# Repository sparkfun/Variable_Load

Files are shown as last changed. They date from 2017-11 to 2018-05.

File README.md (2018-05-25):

SparkFun Variable Load
==========================================

Variable Load

[*Variable Load (KIT-14449)*](https://www.sparkfun.com/products/14449)

The Variable Load is a digitally controllable load for testing power supplies.
It can test up to 30V at 4A, with a limit of 15W.

Repository Contents
-------------------
* **/Hardware** - All Eagle design files (.brd, .sch)
* **/Firmware** - Firmware files for this project.
* **/Production** - Test bed files and production panel files

Documentation
--------------

* **[Hookup Guide - Revised](https://learn.sparkfun.com/tutorials/variable-load-hookup-guide---revised)** - Latest basic hookup guide for the Variable Load.
* ***[Hookup Guide (RETIRED)](https://learn.sparkfun.com/tutorials/variable-load-hookup-guide)** - Basic hookup guide for the Variable Load for boards purchased purchased prior to 24 May 2018.*

License Information
-------------------

This product is _**open source**_! 

Please review the LICENSE.md file for license information. 

If you have any questions or concerns on licensing, please contact techsupport@sparkfun.com.

Distributed as-is; no warranty is given.

- Your friends at SparkFun.

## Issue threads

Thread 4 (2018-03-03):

PID issue with negative error

keck9939, 2018-03-03:
If the error term in the PID calculation is negative, I believe the PID calculation falls apart. For example, if iLimit is 1.0 and iSource is 1.1, it calculates grossSetPoint = 0, fineSetPoint = 65533. Since for iSource = 0.9 you get grossSetPoint = 1 and fineSetPoint = 2, and for 0 error you get 0, there is clearly something wrong (the PID output should be a continuous function of the input). Looking at the code, it is clear there was no thought given to handling negative PID output. While it is possible the load may appear to operate correctly, I strongly suspect it is subject to overshoot and instability.

calston, 2018-04-22:
I think this is the same issue I’m reproducing when the supply current limits and the I value goes below the loads limit setting. Your fix is a total rewrite though, which is a bit hard to review although probably not unwarranted given the quality

But since apparently no one at Sparkfun cares about this product sucking horribly maybe we should just fork this off to a different project so PRs actually go anywhere?

keck9939, 2018-04-22:
I rewrote it since I found there were a number of short comings and I wanted to add a mAh computation to use it to evaluate batteries. I forked it (keck9939/Variable_Load), but I am a GitHub newbie so I was hoping Sparkfun would respond to my pull request so I didn't have to become a maintainer. I doubt it is a hot seller which may explain Sparkfun's lack of interest. I would not have bought it if I didn't already have experience with PSoCs since I figured I'd want to modify it.

calston, 2018-04-23:
I also intended to modify it but was not expecting how expensive that would be.

keck9939, 2018-04-23:
FYI, the cheapest way to get a programmer is to buy one of the Cypress PSoC dev boards. For example the CY8KIT-059 is $15. It includes a breakaway KitProg which can be used to program the Sparkfun board. Much cheaper than buying a MiniProg. And you might even find a use for the dev board (PSoCs rock!)

calston, 2018-04-23:
I've ordered one of those but $15 turns into much more with customs and shipping to the middle of nowhere here...

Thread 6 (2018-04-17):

Enable/disable load via serial

calston, 2018-04-17:
I'm not entirely sure how to implement this, but it would be nice to be able to enable the load remotely rather than the buttons.

calston, 2018-04-17:
Gees, apparently I have to buy a dev kit just to reflash this thing

keck9939, 2018-04-22:
Cypress provides a boot-load system that would allow re-flashing without a programmer. Unfortunately, Sparkfun did not implement it.

jbcall90, 2021-07-04:
Per the revised Variable Load Hookup Guide, boards shipped after 24 May 2018 include the bootloader. The revised Variable Load Hookup Guide includes detailed and adequate instructions on how to use PSoC Creator to upload firmware changes.

The firmware included on the kit I received in June 2021 includes the feature to enable and disable the load using the serial connection.

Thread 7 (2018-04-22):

Variable load behaves unexpectedly on a current limited source

calston, 2018-04-22:
Connecting the Variable Load to a current limited source yields highly unexpected results.

The load shuts off entirely letting the source recover somewhat and then turns on again, cycling like that without equilibrium

mhord, 2018-04-23:
This is exactly the behavior I would expect:
1. The supply's current limit is exceeded.
2. The supply voltage folds back.
3. Supply voltage drops below variable load minimum voltage.
4. Variable load shuts off since its minimum voltage check has been violated.
5. No load on supply so supply exits foldback and rebounds.
6. Etc.

calston, 2018-04-24:
That makes no sense at all. The load is a current device, the voltage from the limited supply drops slightly to maintain constant power. Why on earth would the load shut itself off when the voltage reduces only slightly?

calston, 2018-04-24:
The virtual resistance of the load should increase proportional to the voltage to maintain a constant load. Instead it shuts off? Did you actually test this before rubbishing my ticket?

mhord, 2018-04-24:
The new version of firmware will disable the output until a user intervenes when the input dips below Vmin. That will prevent the cycling behavior you've seen.

mhord, 2018-04-24:
You'll note that I didn't say that the supply "shuts down", I said it "folds back". That means reducing the voltage until the current stabilizes at the limit.

The variable load won't attempt to keep drawing current if the voltage is below 2V. I suspect that if you were to watch the output of your load on a scope you'd see it oscillating above and below 2V as the load kicks on and off. Can you verify this? Again, that's the expected outcome.

The newer version of the code, contributed by keck9939, disables the load once the voltage dips below 2V and doesn't reenable it until the user intervenes. I find this to be a preferable state of affairs.

Closed 2018-04-23.

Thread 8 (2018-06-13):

V Source limits at 20.48V

steaky1212, 2018-06-13:
V Source will not exceed 20.48V

steaky1212, 2018-06-13:
Somehow TopDesign.cysch Page1 Source_ADC was set to "0.0 to 2.048V" instead of "Vssa to Vdda".
Once changed to "Vssa to Vdda" this worked fine again

Closed 2018-06-13.

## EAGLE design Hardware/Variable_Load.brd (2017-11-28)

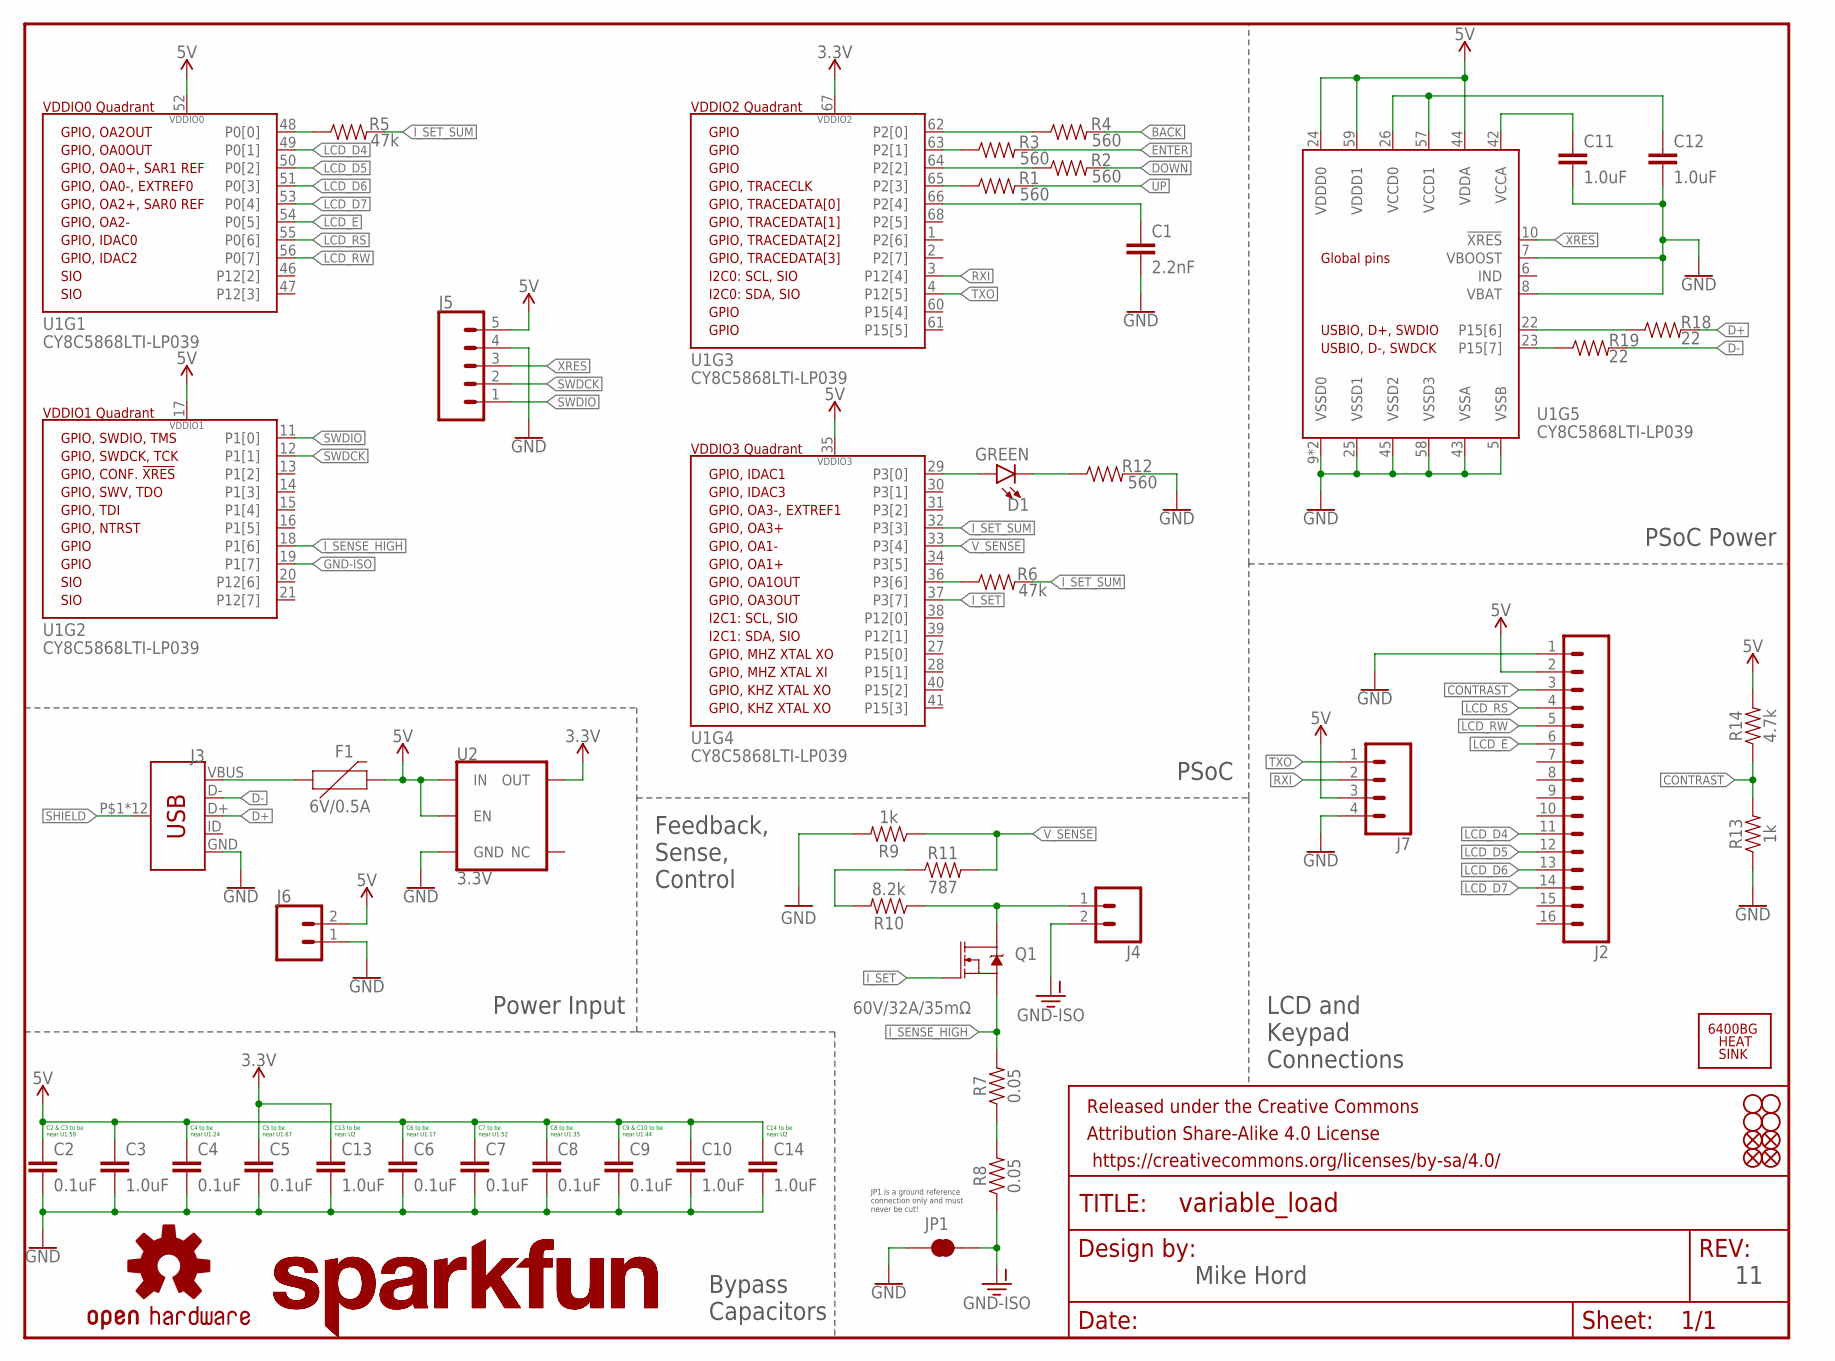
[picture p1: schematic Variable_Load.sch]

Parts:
C1: 2.2nF; 0603
C2, C4, C5, C6, C7, C8, C9: 0.1uF; 0402
C3, C10, C11, C12, C13, C14: 1.0uF; 0402
D1: GREEN; LED-1206-BOTTOM
F1: 6V/0.5A; 1206
FD1, FD2, FD3, FD4: FIDUCIAL1X2; FIDUCIAL-1X2
FRAME1: FRAME-LETTER; CREATIVE_COMMONS
H1: 6400BG_HEATSINK
H2, H3, H4, H5: STAND-OFF
J2: CONN_16; 1X16
J3: AMP FCI 10103594-0001LF; USB-MICROB-PTH
J4: CONN_023.5MM_LOCK; SCREWTERMINAL-3.5MM-2_LOCK
J5: CONN_05; 1X05
J6: CONN_02; 1X02
J7: CONN_04; 1X04
JP1: JUMPER-SMT_2_NC_TRACE_NO-SILK; SMT-JUMPER_2_NC_TRACE_NO-SILK
LOGO1: OSHW-LOGOM; OSHW-LOGO-M
LOGO2, LOGO3: SFE_LOGO_NAME.3_INCH; SFE_LOGO_NAME_.3
Q1: 60V/32A/35mΩ; TO220V
R1, R2, R3, R4, R12: 560; 0402
R5, R6: 47k; 0603
R7, R8: 0.05; 2512
R9, R13: 1k; 0603
R10: 8.2k; 0603
R11: 787; 0603
R14: 4.7k; 0603
R18, R19: 22; 0402-RES
U1: CY8C5868LTI-LP039; QFN-68
U2: 3.3V; SOT23-5

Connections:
3.3V: C5.1, C13.1, U1.67 (VDDIO2), U2.5 (OUT)
5V: C2.1, C3.1, C4.1, C6.1, C7.1, C8.1, C9.1, C10.1, C14.1, F1.2, J2.2, J5.5, J6.2, J7.3, R14.2, U1.17 (VDDIO1), U1.24 (VDDD0), U1.35 (VDDIO3), U1.44 (VDDA), U1.52 (VDDIO0), U1.59 (VDDD1), U2.1 (IN), U2.3 (EN)
BACK: R4.2
CONTRAST: J2.3, R13.2, R14.1
D+: J3.D+, R18.2
D-: J3.D-, R19.2
DOWN: R2.2
ENTER: R3.2
GND: C1.2, C2.2, C3.2, C4.2, C5.2, C6.2, C7.2, C8.2, C9.2, C10.2, C11.2, C12.2, C13.2, C14.2, J2.1, J3.GND, J5.4, J6.1, J7.4, JP1.1, R9.2, R12.2, R13.1, U1.5 (VSSB), U1.7 (VBOOST), U1.8 (VBAT), U1.9 (VSSD0), U1.25 (VSSD1), U1.43 (VSSA), U1.45 (VSSD2), U1.58 (VSSD3), U1.69 (VSSD0), U2.2 (GND)
GND-ISO: J4.2, JP1.2, R8.P$1 (1), U1.19 (P1[7])
I_SENSE_HIGH: Q1.3 (S), R7.P$2 (2), U1.18 (P1[6])
I_SET: Q1.1 (G), U1.37 (P3[7])
I_SET_SUM: R5.2, R6.2, U1.32 (P3[3])
LCD_D4: J2.11, U1.49 (P0[1])
LCD_D5: J2.12, U1.50 (P0[2])
LCD_D6: J2.13, U1.51 (P0[3])
LCD_D7: J2.14, U1.53 (P0[4])
LCD_E: J2.6, U1.54 (P0[5])
LCD_RS: J2.4, U1.55 (P0[6])
LCD_RW: J2.5, U1.56 (P0[7])
unnamed: R1.1, U1.65 (P2[3])
unnamed: R2.1, U1.64 (P2[2])
unnamed: R3.1, U1.63 (P2[1])
unnamed: R4.1, U1.62 (P2[0])
unnamed: C1.1, U1.66 (P2[4])
unnamed: C12.1, U1.26 (VCCD0), U1.57 (VCCD1)
unnamed: C11.1, U1.42 (VCCA)
unnamed: R18.1, U1.22 (P15[6])
unnamed: R19.1, U1.23 (P15[7])
unnamed: R5.1, U1.48 (P0[0])
unnamed: R6.1, U1.36 (P3[6])
unnamed: D1.A, U1.29 (P3[0])
unnamed: D1.C, R12.1
unnamed: F1.1, J3.VBUS
unnamed: J4.1, Q1.2 (D), R10.1
unnamed: R10.2, R11.1
unnamed: R7.P$1 (1), R8.P$2 (2)
RXI: J7.2, U1.3 (P12[4])
SHIELD: J3.P$1 (SHIELD), J3.P$2 (SHIELD), J3.P$3 (SHIELD), J3.P$4 (SHIELD), J3.P$6 (SHIELD), J3.P$8 (SHIELD), J3.P$10 (SHIELD), J3.P$12 (SHIELD), J3.SHEILD2 (SHIELD), J3.SHIELD, J3.SHIELD3 (SHIELD), J3.SHIELD4 (SHIELD)
SWDCK: J5.2, U1.12 (P1[1])
SWDIO: J5.1, U1.11 (P1[0])
TXO: J7.1, U1.4 (P12[5])
UP: R1.2
V_SENSE: R9.1, R11.2, U1.33 (P3[4])
XRES: J5.3, U1.10 (!XRES)

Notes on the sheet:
C2 & C3 to be near U1.59
C4 to be near U1.24
C5 to be near U1.67
C6 to be near U1.17
C7 to be near U1.52
C8 to be near U1.35
C9 & C10 to be near U1.44
C13 to be near U2
C14 to be near U2
Feedback, Sense, Control
Power Input
LCD and Keypad Connections
PSoC Power
PSoC
Bypass Capacitors
Mike Hord
JP1 is a ground reference connection only and must never be cut!

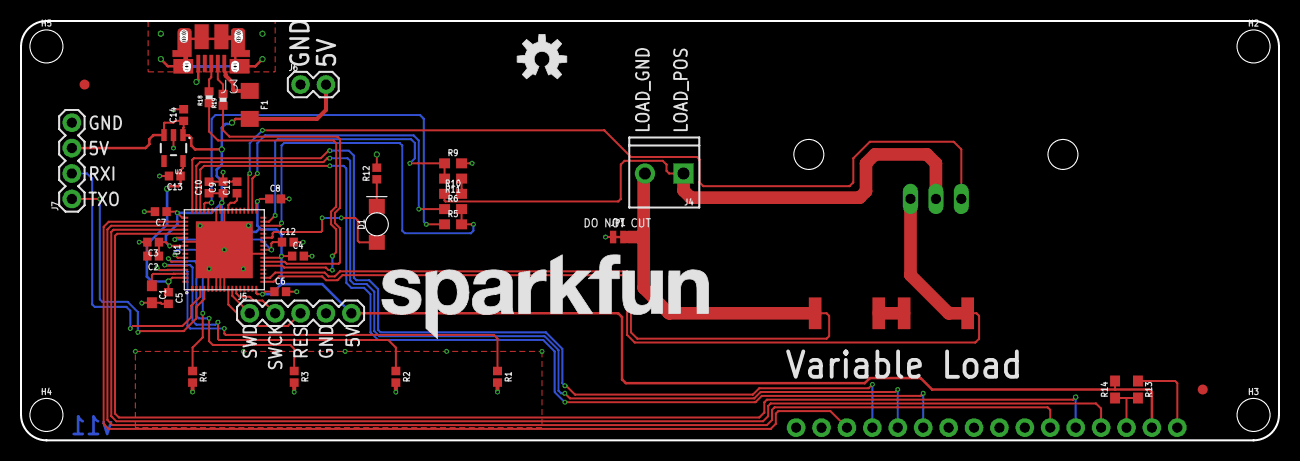
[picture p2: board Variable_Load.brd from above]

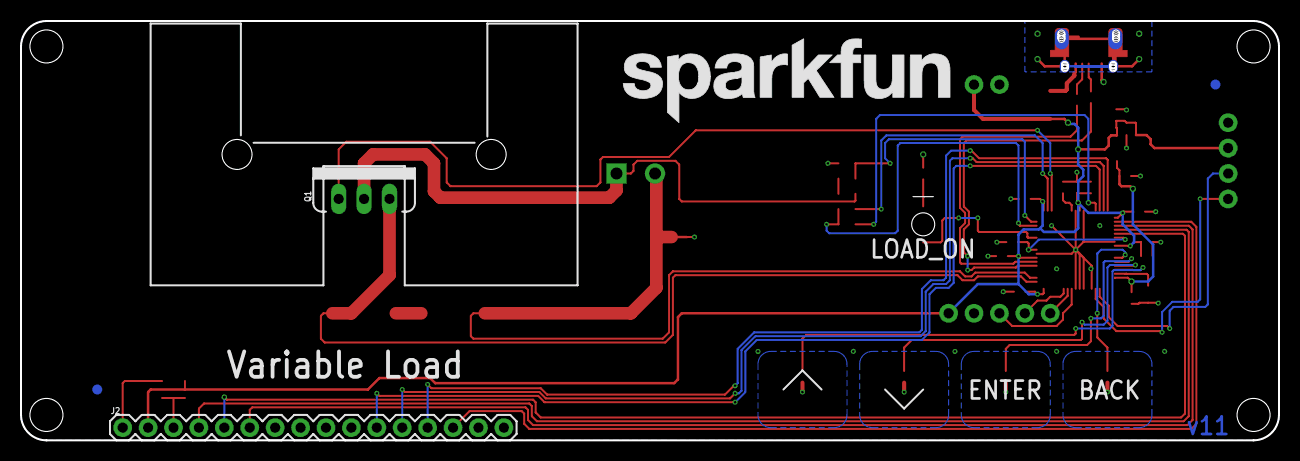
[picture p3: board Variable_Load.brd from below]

Board: 2 copper layers, 125.7 x 41.9 mm, 55 parts (6 on the bottom side), 41 nets.

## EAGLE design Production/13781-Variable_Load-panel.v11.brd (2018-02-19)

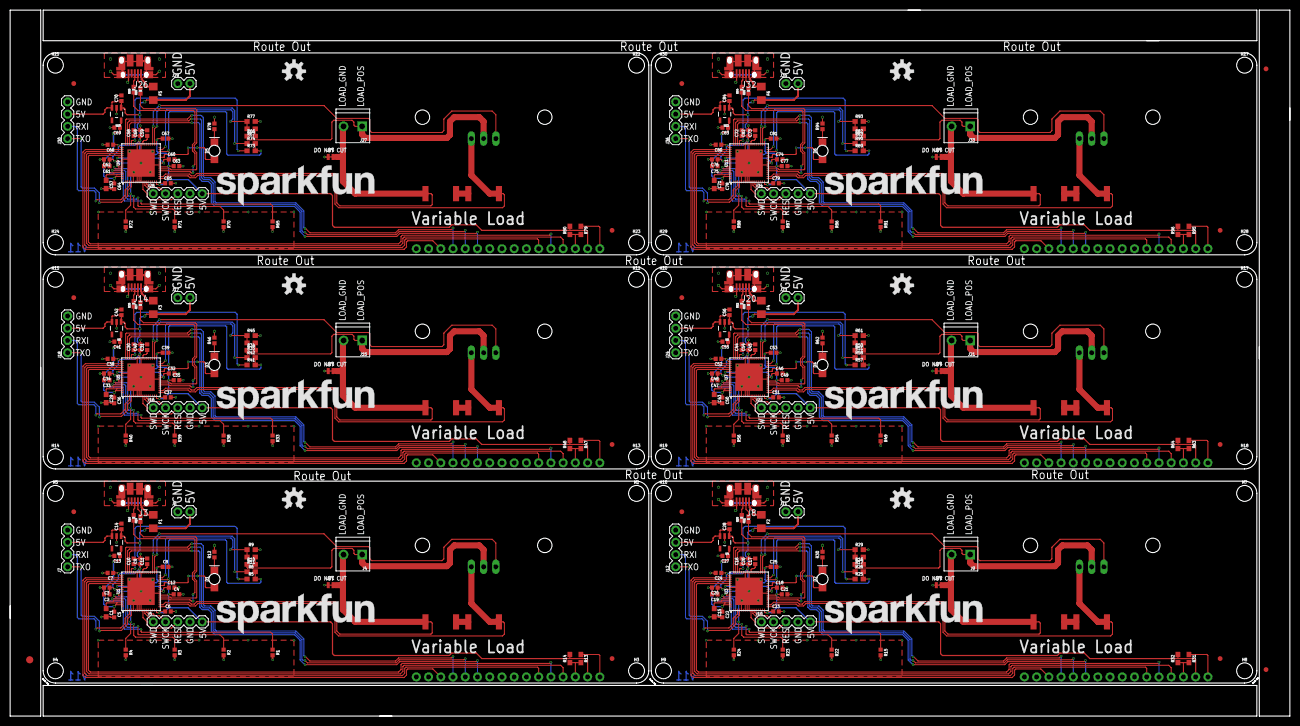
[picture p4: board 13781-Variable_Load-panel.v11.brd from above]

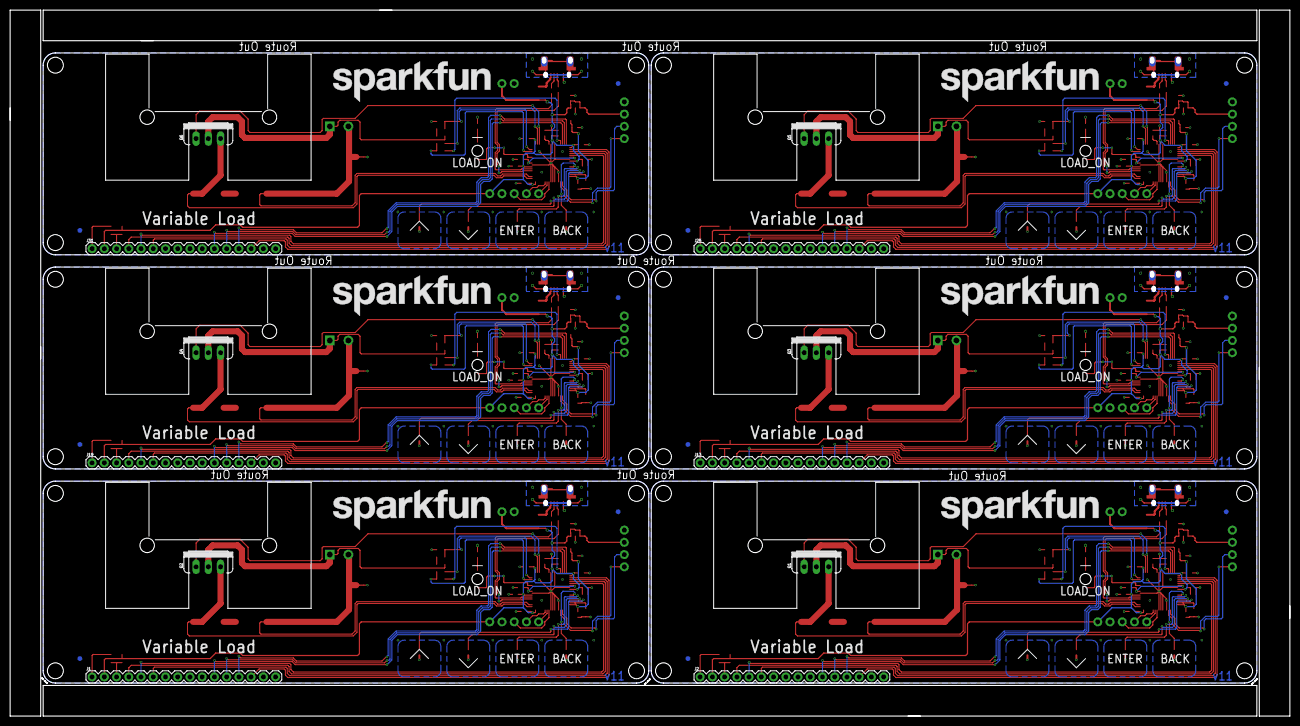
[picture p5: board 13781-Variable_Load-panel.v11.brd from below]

Board: 2 copper layers, 265.7 x 146.6 mm, 327 parts (36 on the bottom side), 246 nets.

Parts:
C1, C15, C29, C43, C57, C71: 2.2nF; 0603
C2, C4, C5, C6, C7, C8, C9, C19, C21, C22, C23, C24, C25, C26, C33, C35, C36, C37, C38, C39, C40, C47, C49, C50, C51, C52, C53, C54, C61, C63, C64, C65, C66, C67, C68, C75, C77, C78, C79, C80, C81, C82: 0.1uF; 0402
C3, C10, C11, C12, C13, C14, C16, C17, C18, C20, C27, C28, C30, C31, C32, C34, C41, C42, C44, C45, C46, C48, C55, C56, C58, C59, C60, C62, C69, C70, C72, C73, C74, C76, C83, C84: 1.0uF; 0402
D1, D2, D3, D4, D5, D6: GREEN; LED-1206-BOTTOM
E$1: FIDUCIAL-1.5X3
E$7, E$8: FIDUCIAL-1X2
F1, F2, F3, F4, F5, F6: 6V/0.5A; 1206
FD1, FD2, FD3, FD4, FD5, FD6, FD7, FD8, FD9, FD10, FD11, FD12, FD13, FD14, FD15, FD16, FD17, FD18, FD19, FD20, FD21, FD22, FD23, FD24: FIDUCIAL1X2; FIDUCIAL-1X2
H1, H6, H11, H16, H21, H26: 6400BG_HEATSINK
H2, H3, H4, H5, H7, H8, H9, H10, H12, H13, H14, H15, H17, H18, H19, H20, H22, H23, H24, H25, H27, H28, H29, H30: STAND-OFF
J1, J2, J13, J19, J25, J31: 1X16
J3, J8, J14, J20, J26, J32: AMP FCI 10103594-0001LF; USB-MICROB-PTH
J4, J9, J15, J21, J27, J33: SCREWTERMINAL-3.5MM-2_LOCK
J5, J10, J16, J22, J28, J34: 1X05
J6, J11, J17, J23, J29, J35: 1X02
J7, J12, J18, J24, J30, J36: 1X04
JP1, JP2, JP3, JP4, JP5, JP6: JUMPER-SMT_2_NC_TRACE_NO-SILK; SMT-JUMPER_2_NC_TRACE_NO-SILK
LOGO1, LOGO4, LOGO7, LOGO10, LOGO13, LOGO16: OSHW-LOGOM; OSHW-LOGO-M
LOGO2, LOGO3, LOGO5, LOGO6, LOGO8, LOGO9, LOGO11, LOGO12, LOGO14, LOGO15, LOGO17, LOGO18: SFE_LOGO_NAME.3_INCH; SFE_LOGO_NAME_.3
Q1, Q2, Q3, Q4, Q5, Q6: 60V/32A/35mΩ; TO220V
R1, R2, R3, R4, R12, R15, R22, R23, R24, R30, R33, R38, R39, R40, R46, R49, R54, R55, R56, R62, R65, R70, R71, R72, R78, R81, R86, R87, R88, R94: 560; 0402
R5, R6, R25, R26, R41, R42, R57, R58, R73, R74, R89, R90: 47k; 0603
R7, R8, R27, R28, R43, R44, R59, R60, R75, R76, R91, R92: 0.05; 2512
R9, R13, R29, R31, R45, R47, R61, R63, R77, R79, R93, R95: 1k; 0603
R10, R16, R34, R50, R66, R82: 8.2k; 0603
R11, R17, R35, R51, R67, R83: 787; 0603
R14, R32, R48, R64, R80, R96: 4.7k; 0603
R18, R19, R20, R21, R36, R37, R52, R53, R68, R69, R84, R85: 22; 0402-RES
U1, U3, U5, U7, U9, U11: CY8C5868LTI-LP039; QFN-68
U2, U4, U6, U8, U10, U12: 3.3V; SOT23-5

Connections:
3.3V: C5.1, C13.1, U1.67, U2.5
3.3V1: C22.1, C27.1, U3.67, U4.5
3.3V2: C36.1, C41.1, U5.67, U6.5
3.3V3: C50.1, C55.1, U7.67, U8.5
3.3V4: C64.1, C69.1, U9.67, U10.5
3.3V5: C78.1, C83.1, U11.67, U12.5
5V: C2.1, C3.1, C4.1, C6.1, C7.1, C8.1, C9.1, C10.1, C14.1, F1.2, J2.2, J5.5, J6.2, J7.3, R14.2, U1.17, U1.24, U1.35, U1.44, U1.52, U1.59, U2.1, U2.3
5V1: C16.1, C19.1, C20.1, C21.1, C23.1, C24.1, C25.1, C26.1, C28.1, F2.2, J1.2, J10.5, J11.2, J12.3, R32.2, U3.17, U3.24, U3.35, U3.44, U3.52, U3.59, U4.1, U4.3
5V2: C30.1, C33.1, C34.1, C35.1, C37.1, C38.1, C39.1, C40.1, C42.1, F3.2, J13.2, J16.5, J17.2, J18.3, R48.2, U5.17, U5.24, U5.35, U5.44, U5.52, U5.59, U6.1, U6.3
5V3: C44.1, C47.1, C48.1, C49.1, C51.1, C52.1, C53.1, C54.1, C56.1, F4.2, J19.2, J22.5, J23.2, J24.3, R64.2, U7.17, U7.24, U7.35, U7.44, U7.52, U7.59, U8.1, U8.3
5V4: C58.1, C61.1, C62.1, C63.1, C65.1, C66.1, C67.1, C68.1, C70.1, F5.2, J25.2, J28.5, J29.2, J30.3, R80.2, U9.17, U9.24, U9.35, U9.44, U9.52, U9.59, U10.1, U10.3
5V5: C72.1, C75.1, C76.1, C77.1, C79.1, C80.1, C81.1, C82.1, C84.1, F6.2, J31.2, J34.5, J35.2, J36.3, R96.2, U11.17, U11.24, U11.35, U11.44, U11.52, U11.59, U12.1, U12.3
CONTRAST: J2.3, R13.2, R14.1
CONTRAST1: J1.3, R31.2, R32.1
CONTRAST2: J13.3, R47.2, R48.1
CONTRAST3: J19.3, R63.2, R64.1
CONTRAST4: J25.3, R79.2, R80.1
CONTRAST5: J31.3, R95.2, R96.1
D+: J3.D+, R18.2
D+1: J8.D+, R20.2
D+2: J14.D+, R36.2
D+3: J20.D+, R52.2
D+4: J26.D+, R68.2
D+5: J32.D+, R84.2
D-: J3.D-, R19.2
D-1: J8.D-, R21.2
D-2: J14.D-, R37.2
D-3: J20.D-, R53.2
D-4: J26.D-, R69.2
D-5: J32.D-, R85.2
GND: C1.2, C2.2, C3.2, C4.2, C5.2, C6.2, C7.2, C8.2, C9.2, C10.2, C11.2, C12.2, C13.2, C14.2, J2.1, J3.GND, J5.4, J6.1, J7.4, JP1.1, R9.2, R12.2, R13.1, U1.5, U1.7, U1.8, U1.9, U1.25, U1.43, U1.45, U1.58, U1.69, U2.2
GND1: C15.2, C16.2, C17.2, C18.2, C19.2, C20.2, C21.2, C22.2, C23.2, C24.2, C25.2, C26.2, C27.2, C28.2, J1.1, J8.GND, J10.4, J11.1, J12.4, JP2.1, R29.2, R30.2, R31.1, U3.5, U3.7, U3.8, U3.9, U3.25, U3.43, U3.45, U3.58, U3.69, U4.2
GND2: C29.2, C30.2, C31.2, C32.2, C33.2, C34.2, C35.2, C36.2, C37.2, C38.2, C39.2, C40.2, C41.2, C42.2, J13.1, J14.GND, J16.4, J17.1, J18.4, JP3.1, R45.2, R46.2, R47.1, U5.5, U5.7, U5.8, U5.9, U5.25, U5.43, U5.45, U5.58, U5.69, U6.2
GND3: C43.2, C44.2, C45.2, C46.2, C47.2, C48.2, C49.2, C50.2, C51.2, C52.2, C53.2, C54.2, C55.2, C56.2, J19.1, J20.GND, J22.4, J23.1, J24.4, JP4.1, R61.2, R62.2, R63.1, U7.5, U7.7, U7.8, U7.9, U7.25, U7.43, U7.45, U7.58, U7.69, U8.2
GND4: C57.2, C58.2, C59.2, C60.2, C61.2, C62.2, C63.2, C64.2, C65.2, C66.2, C67.2, C68.2, C69.2, C70.2, J25.1, J26.GND, J28.4, J29.1, J30.4, JP5.1, R77.2, R78.2, R79.1, U9.5, U9.7, U9.8, U9.9, U9.25, U9.43, U9.45, U9.58, U9.69, U10.2
GND5: C71.2, C72.2, C73.2, C74.2, C75.2, C76.2, C77.2, C78.2, C79.2, C80.2, C81.2, C82.2, C83.2, C84.2, J31.1, J32.GND, J34.4, J35.1, J36.4, JP6.1, R93.2, R94.2, R95.1, U11.5, U11.7, U11.8, U11.9, U11.25, U11.43, U11.45, U11.58, U11.69, U12.2
GND-ISO: J4.2, JP1.2, R8.P$1, U1.19
GND-ISO1: J9.2, JP2.2, R28.P$1, U3.19
GND-ISO2: J15.2, JP3.2, R44.P$1, U5.19
GND-ISO3: J21.2, JP4.2, R60.P$1, U7.19
GND-ISO4: J27.2, JP5.2, R76.P$1, U9.19
GND-ISO5: J33.2, JP6.2, R92.P$1, U11.19
I_SENSE_HIGH: Q1.3, R7.P$2, U1.18
I_SENSE_HIGH1: Q2.3, R27.P$2, U3.18
I_SENSE_HIGH2: Q3.3, R43.P$2, U5.18
I_SENSE_HIGH3: Q4.3, R59.P$2, U7.18
I_SENSE_HIGH4: Q5.3, R75.P$2, U9.18
I_SENSE_HIGH5: Q6.3, R91.P$2, U11.18
I_SET: Q1.1, U1.37
I_SET1: Q2.1, U3.37
I_SET2: Q3.1, U5.37
I_SET3: Q4.1, U7.37
I_SET4: Q5.1, U9.37
I_SET5: Q6.1, U11.37
I_SET_SUM: R5.2, R6.2, U1.32
I_SET_SUM1: R25.2, R26.2, U3.32
I_SET_SUM2: R41.2, R42.2, U5.32
I_SET_SUM3: R57.2, R58.2, U7.32
I_SET_SUM4: R73.2, R74.2, U9.32
I_SET_SUM5: R89.2, R90.2, U11.32
LCD_D1: J1.11, U3.49
LCD_D2: J1.12, U3.50
LCD_D3: J1.13, U3.51
LCD_D4: J2.11, U1.49
LCD_D5: J2.12, U1.50
LCD_D6: J2.13, U1.51
LCD_D7: J2.14, U1.53
LCD_D8: J1.14, U3.53
LCD_D9: J13.11, U5.49
LCD_D10: J13.12, U5.50
LCD_D11: J13.13, U5.51
LCD_D12: J13.14, U5.53
LCD_D13: J19.11, U7.49
LCD_D14: J19.12, U7.50
LCD_D15: J19.13, U7.51
LCD_D16: J19.14, U7.53
LCD_D17: J25.11, U9.49
LCD_D18: J25.12, U9.50
LCD_D19: J25.13, U9.51
LCD_D20: J25.14, U9.53
LCD_D21: J31.11, U11.49
LCD_D22: J31.12, U11.50
LCD_D23: J31.13, U11.51
LCD_D24: J31.14, U11.53
LCD_E: J2.6, U1.54
LCD_E1: J1.6, U3.54
LCD_E2: J13.6, U5.54
LCD_E3: J19.6, U7.54
LCD_E4: J25.6, U9.54
LCD_E5: J31.6, U11.54
LCD_RS: J2.4, U1.55
LCD_RS1: J1.4, U3.55
LCD_RS2: J13.4, U5.55
LCD_RS3: J19.4, U7.55
LCD_RS4: J25.4, U9.55
LCD_RS5: J31.4, U11.55
LCD_RW: J2.5, U1.56
LCD_RW1: J1.5, U3.56
LCD_RW2: J13.5, U5.56
LCD_RW3: J19.5, U7.56
LCD_RW4: J25.5, U9.56
LCD_RW5: J31.5, U11.56
unnamed: R1.1, U1.65
unnamed: R2.1, U1.64
unnamed: R3.1, U1.63
unnamed: R4.1, U1.62
unnamed: C1.1, U1.66
unnamed: C12.1, U1.26, U1.57
unnamed: C11.1, U1.42
unnamed: R18.1, U1.22
unnamed: R19.1, U1.23
unnamed: R5.1, U1.48
unnamed: R6.1, U1.36
unnamed: D1.A, U1.29
unnamed: D1.C, R12.1
unnamed: F1.1, J3.VBUS
unnamed: J4.1, Q1.2, R10.1
unnamed: R10.2, R11.1
unnamed: C15.1, U3.66
unnamed: R7.P$1, R8.P$2
unnamed: R25.1, U3.48
unnamed: C18.1, U3.26, U3.57
unnamed: C17.1, U3.42
unnamed: R20.1, U3.22
unnamed: R21.1, U3.23
unnamed: F2.1, J8.VBUS
unnamed: J9.1, Q2.2, R16.1
unnamed: R16.2, R17.1
unnamed: R27.P$1, R28.P$2
unnamed: R15.1, U3.65
unnamed: R22.1, U3.64
unnamed: R23.1, U3.63
unnamed: R24.1, U3.62
unnamed: R26.1, U3.36
unnamed: D2.A, U3.29
unnamed: D2.C, R30.1
unnamed: C29.1, U5.66
unnamed: R41.1, U5.48
unnamed: C32.1, U5.26, U5.57
unnamed: C31.1, U5.42
unnamed: R36.1, U5.22
unnamed: R37.1, U5.23
unnamed: F3.1, J14.VBUS
unnamed: J15.1, Q3.2, R34.1
unnamed: R34.2, R35.1
unnamed: R43.P$1, R44.P$2
unnamed: R33.1, U5.65
unnamed: R38.1, U5.64
unnamed: R39.1, U5.63
unnamed: R40.1, U5.62
unnamed: R42.1, U5.36
unnamed: D3.A, U5.29
unnamed: D3.C, R46.1
unnamed: C43.1, U7.66
unnamed: R57.1, U7.48
unnamed: C46.1, U7.26, U7.57
unnamed: C45.1, U7.42
unnamed: R52.1, U7.22
unnamed: R53.1, U7.23
unnamed: F4.1, J20.VBUS
unnamed: J21.1, Q4.2, R50.1
unnamed: R50.2, R51.1
unnamed: R59.P$1, R60.P$2
unnamed: R49.1, U7.65
unnamed: R54.1, U7.64
unnamed: R55.1, U7.63
unnamed: R56.1, U7.62
unnamed: R58.1, U7.36
unnamed: D4.A, U7.29
unnamed: D4.C, R62.1
unnamed: C57.1, U9.66
unnamed: R73.1, U9.48
unnamed: C60.1, U9.26, U9.57
unnamed: C59.1, U9.42
unnamed: R68.1, U9.22
unnamed: R69.1, U9.23
unnamed: F5.1, J26.VBUS
unnamed: J27.1, Q5.2, R66.1
unnamed: R66.2, R67.1
unnamed: R75.P$1, R76.P$2
unnamed: R65.1, U9.65
unnamed: R70.1, U9.64
unnamed: R71.1, U9.63
unnamed: R72.1, U9.62
unnamed: R74.1, U9.36
unnamed: D5.A, U9.29
unnamed: D5.C, R78.1
unnamed: C71.1, U11.66
unnamed: R89.1, U11.48
unnamed: C74.1, U11.26, U11.57
unnamed: C73.1, U11.42
unnamed: R84.1, U11.22
unnamed: R85.1, U11.23
unnamed: F6.1, J32.VBUS
unnamed: J33.1, Q6.2, R82.1
unnamed: R82.2, R83.1
unnamed: R91.P$1, R92.P$2
unnamed: R81.1, U11.65
unnamed: R86.1, U11.64
unnamed: R87.1, U11.63
unnamed: R88.1, U11.62
unnamed: R90.1, U11.36
unnamed: D6.A, U11.29
unnamed: D6.C, R94.1
RXI: J7.2, U1.3
RXI1: J12.2, U3.3
RXI2: J18.2, U5.3
RXI3: J24.2, U7.3
RXI4: J30.2, U9.3
RXI5: J36.2, U11.3
SHIELD: J3.P$1, J3.P$2, J3.P$3, J3.P$4, J3.P$6, J3.P$8, J3.P$10, J3.P$12, J3.SHEILD2, J3.SHIELD, J3.SHIELD3, J3.SHIELD4
SHIELD1: J8.P$1, J8.P$2, J8.P$3, J8.P$4, J8.P$6, J8.P$8, J8.P$10, J8.P$12, J8.SHEILD2, J8.SHIELD, J8.SHIELD3, J8.SHIELD4
SHIELD2: J14.P$1, J14.P$2, J14.P$3, J14.P$4, J14.P$6, J14.P$8, J14.P$10, J14.P$12, J14.SHEILD2, J14.SHIELD, J14.SHIELD3, J14.SHIELD4
SHIELD3: J20.P$1, J20.P$2, J20.P$3, J20.P$4, J20.P$6, J20.P$8, J20.P$10, J20.P$12, J20.SHEILD2, J20.SHIELD, J20.SHIELD3, J20.SHIELD4
SHIELD4: J26.P$1, J26.P$2, J26.P$3, J26.P$4, J26.P$6, J26.P$8, J26.P$10, J26.P$12, J26.SHEILD2, J26.SHIELD, J26.SHIELD3, J26.SHIELD4
SHIELD5: J32.P$1, J32.P$2, J32.P$3, J32.P$4, J32.P$6, J32.P$8, J32.P$10, J32.P$12, J32.SHEILD2, J32.SHIELD, J32.SHIELD3, J32.SHIELD4
SWDCK: J5.2, U1.12
SWDCK1: J10.2, U3.12
SWDCK2: J16.2, U5.12
SWDCK3: J22.2, U7.12
SWDCK4: J28.2, U9.12
SWDCK5: J34.2, U11.12
SWDIO: J5.1, U1.11
SWDIO1: J10.1, U3.11
SWDIO2: J16.1, U5.11
SWDIO3: J22.1, U7.11
SWDIO4: J28.1, U9.11
SWDIO5: J34.1, U11.11
TXO: J7.1, U1.4
TXO1: J12.1, U3.4
TXO2: J18.1, U5.4
TXO3: J24.1, U7.4
TXO4: J30.1, U9.4
TXO5: J36.1, U11.4
V_SENSE: R9.1, R11.2, U1.33
V_SENSE1: R17.2, R29.1, U3.33
V_SENSE2: R35.2, R45.1, U5.33
V_SENSE3: R51.2, R61.1, U7.33
V_SENSE4: R67.2, R77.1, U9.33
V_SENSE5: R83.2, R93.1, U11.33
XRES: J5.3, U1.10
XRES1: J10.3, U3.10
XRES2: J16.3, U5.10
XRES3: J22.3, U7.10
XRES4: J28.3, U9.10
XRES5: J34.3, U11.10

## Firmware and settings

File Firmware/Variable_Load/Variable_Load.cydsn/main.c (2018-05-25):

#include "project.h"
#include <stdbool.h>
#include <stdio.h>
#include <stdlib.h>
#include "terminal.h"

#define KPN 19
#define KPD 100
#define KIN 1
#define KID 10

#define DEFAULT_I_LIM 0
#define DEFAULT_V_MIN 2000

/* Defines for SourceDMA */
#define SourceDMA_BYTES_PER_BURST 2
#define SourceDMA_REQUEST_PER_BURST 1
#define SourceDMA_SRC_BASE (CYDEV_PERIPH_BASE)
#define SourceDMA_DST_BASE (CYDEV_SRAM_BASE)

/* Defines for BufferDMA */
#define BufferDMA_BYTES_PER_BURST 4
#define BufferDMA_REQUEST_PER_BURST 1
#define BufferDMA_SRC_BASE (CYDEV_PERIPH_BASE)
#define BufferDMA_DST_BASE (CYDEV_SRAM_BASE)

/* Variable declarations for BufferDMA */
/* Move these variable declarations to the top of the function */
uint8 BufferDMA_Chan;
uint8 BufferDMA_TD[1];

/* Defines for CurrentDMA */
#define CurrentDMA_BYTES_PER_BURST 4
#define CurrentDMA_REQUEST_PER_BURST 1
#define CurrentDMA_SRC_BASE (CYDEV_SRAM_BASE)
#define CurrentDMA_DST_BASE (CYDEV_SRAM_BASE)

/* Variable declarations for CurrentDMA */
/* Move these variable declarations to the top of the function */
static uint8 CurrentDMA_Chan;
static uint8 CurrentDMA_TD[1];

/* Variable declarations for SourceDMA */
/* Move these variable declarations to the top of the function */
#define ADCSAMPLES 40
static uint8 SourceDMA_Chan;
static uint8 SourceDMA_TD[1];
static volatile uint16 SourceData[ADCSAMPLES];

#define CURRENTSAMPLES 10
static volatile uint32 CurrentReadings[CURRENTSAMPLES];
static uint32 DMABuffer;

void DoPid();
void OutputEnable(bool v);

volatile static int32 systemTimer = 0;

static float fiLimit;
volatile static uint32 iLimit = DEFAULT_I_LIM;
volatile static uint16 vSource = 0;
volatile static int iSource = 0;
volatile static uint32 dt = 0;
volatile static int vMin = DEFAULT_V_MIN;
volatile static uint32 maHours;

bool enableOutput = false;

int main(void)
{
	static int i;
	static uint32 vAve;
	static char buff[64];
  char testBuff[2];
  uint8_t testBuffIndex = 0;
	static uint8 inBuff[64];
	static char floatBuff[64];
	static uint8_t incCharIndex = 0;

	CyGlobalIntEnable; /* Enable global interrupts. */

	// Create our timing "tick" variables. These are used to record when the last
	// iteration of an action in the main loop happened and to trigger the next
	// iteration when some number of clock ticks have passed.
	int32_t SlowTick = 0;

	Gate_Drive_Tune_Start();
	Offset_Start();
	Offset_Gain_Start();
	GDT_Buffer_Start();
	O_Buffer_Start();
	Source_ADC_Start();
	I_Source_ADC_Start();
  UART_Start();

	bool upPressed = false;
	bool downPressed = false;
	bool entPressed = false;
	bool backPressed = false;

	USBUART_Start(0, USBUART_5V_OPERATION);
	CapSense_Start();
	CapSense_InitializeAllBaselines();
	ConversionClock_Start();
	LCD_Start();
	LCD_DisplayOn();
	LCD_PrintString("Hello, world");

	/* DMA Configuration for SourceDMA */
	SourceDMA_Chan = SourceDMA_DmaInitialize(SourceDMA_BYTES_PER_BURST, SourceDMA_REQUEST_PER_BURST,
		HI16(SourceDMA_SRC_BASE), HI16(SourceDMA_DST_BASE));
	SourceDMA_TD[0] = CyDmaTdAllocate();
	CyDmaTdSetConfiguration(SourceDMA_TD[0], 2 * ADCSAMPLES, SourceDMA_TD[0], CY_DMA_TD_INC_DST_ADR);
	CyDmaTdSetAddress(SourceDMA_TD[0], LO16((uint32)Source_ADC_SAR_WRK0_PTR), LO16((uint32)SourceData));
	CyDmaChSetInitialTd(SourceDMA_Chan, SourceDMA_TD[0]);
	Source_ADC_StartConvert();
	CyDmaChEnable(SourceDMA_Chan, 1);

	/* DMA Configuration for BufferDMA */

	BufferDMA_Chan = BufferDMA_DmaInitialize(BufferDMA_BYTES_PER_BURST, BufferDMA_REQUEST_PER_BURST,
		HI16(BufferDMA_SRC_BASE), HI16(BufferDMA_DST_BASE));
	BufferDMA_TD[0] = CyDmaTdAllocate();
	CyDmaTdSetConfiguration(BufferDMA_TD[0], 4, BufferDMA_TD[0], TD_INC_SRC_ADR | BufferDMA__TD_TERMOUT_EN);
	CyDmaTdSetAddress(BufferDMA_TD[0], LO16((uint32)I_Source_ADC_DEC_SAMP_PTR), LO16((uint32)DMABuffer));
	CyDmaChSetInitialTd(BufferDMA_Chan, BufferDMA_TD[0]);

	/* DMA Configuration for CurrentDMA */
	CurrentDMA_Chan = CurrentDMA_DmaInitialize(CurrentDMA_BYTES_PER_BURST, CurrentDMA_REQUEST_PER_BURST,
		HI16(CurrentDMA_SRC_BASE), HI16(CurrentDMA_DST_BASE));
	CurrentDMA_TD[0] = CyDmaTdAllocate();
	CyDmaTdSetConfiguration(CurrentDMA_TD[0], 4 * CURRENTSAMPLES, CurrentDMA_TD[0], TD_INC_DST_ADR | CurrentDMA__TD_TERMOUT_EN);
	CyDmaTdSetAddress(CurrentDMA_TD[0], LO16((uint32)DMABuffer), LO16((uint32)CurrentReadings));
	CyDmaChSetInitialTd(CurrentDMA_Chan, CurrentDMA_TD[0]);

	/*Change the ADC coherent key to high byte*/
	I_Source_ADC_DEC_COHER_REG |= I_Source_ADC_DEC_SAMP_KEY_HIGH;
	I_Source_ADC_StartConvert();
	CyDmaChEnable(BufferDMA_Chan, 1);
	CyDmaChEnable(CurrentDMA_Chan, 1);

	PIDIsr_Start();

	init();

	for (;;)
	{
		if (0u != USBUART_IsConfigurationChanged())
		{
			if (0u != USBUART_GetConfiguration())
			{
				USBUART_CDC_Init();
			}
		}
    if (0u != USBUART_IsConfigurationChanged())
    {
      if (0u != USBUART_GetConfiguration())
      {
        USBUART_CDC_Init();
      }
    }
    
    // UART is used during production test to test programming
    //  of chip. Test fixture issues '1', expects response of '2'.
    if (UART_GetRxBufferSize())
    {
      while (UART_GetRxBufferSize())
      {
        testBuff[testBuffIndex++] = UART_GetChar();
      }
      if (testBuff[testBuffIndex - 1] == '1')
      {
        UART_PutChar('2');
      }
    }
    if (testBuffIndex > 1)
    {
      testBuffIndex = 0;
      testBuff[0] = '\0';
      testBuff[1] = '\0';
    }
    
		if (0u == CapSense_IsBusy())
		{
			CapSense_UpdateEnabledBaselines();
			CapSense_ScanEnabledWidgets();
		}

		// Handle a press of the back key
		if (CapSense_CheckIsWidgetActive(CapSense_BACK__BTN) && backPressed == false)
		{
			backPressed = true;
			iLimit = DEFAULT_I_LIM;
			vMin = DEFAULT_V_MIN;
			OutputEnable(false);
		}
		else if (!CapSense_CheckIsWidgetActive(CapSense_BACK__BTN) && backPressed == true)
		{
			backPressed = false;
		}

		if (CapSense_CheckIsWidgetActive(CapSense_ENTER__BTN) && entPressed == false)
		{
			entPressed = true;
			OutputEnable(!enableOutput);
		}
		else if (!CapSense_CheckIsWidgetActive(CapSense_ENTER__BTN) && entPressed == true)
		{
			entPressed = false;
		}

		if (CapSense_CheckIsWidgetActive(CapSense_DOWN__BTN) && downPressed == false)
		{
			downPressed = true;
			if (iLimit < 10) iLimit = 0;
			else if (iLimit < 101) { if (iLimit >= 10) iLimit -= 10; }
			else if (iLimit < 501) iLimit -= 50;
			else if (iLimit < 1001) iLimit -= 100;
			else iLimit -= 500;
		}
		else if (!CapSense_CheckIsWidgetActive(CapSense_DOWN__BTN) && downPressed == true)
		{
			downPressed = false;
		}

		if (CapSense_CheckIsWidgetActive(CapSense_UP__BTN) && upPressed == false)
		{
			upPressed = true;
			if (iLimit < 99) iLimit += 10;
			else if (iLimit < 500) iLimit += 50;
			else if (iLimit < 1000) iLimit += 100;
			else if (iLimit < 3500) iLimit += 500;
			else iLimit = 4000;
		}
		else if (!CapSense_CheckIsWidgetActive(CapSense_UP__BTN) && upPressed == true)
		{
			upPressed = false;
		}


		// Fetch any waiting characters from the USB UART.
		int charCount = USBUART_GetCount();
		if (charCount > 0)
		{
			int i = USBUART_GetAll(inBuff);

			for (i = 0; i < charCount; i++)
			{
				floatBuff[incCharIndex++] = inBuff[i];
				if (incCharIndex > 63)
					incCharIndex = 0;
				if (inBuff[i] == '\r' ||
					inBuff[i] == '\n')
				{
					floatBuff[incCharIndex] = '\0';
					break;
				}
			}
		}

		// Average the DMA data from the Source Voltage ADC
		vAve = 0;
		for (i = 0; i < ADCSAMPLES; i++)
			vAve += SourceData[i];

    vAve = vAve/40;
		vSource = 10*Source_ADC_CountsTo_mVolts((uint16)(vAve)); // 10*vAve/40
		if (systemTimer - 20 > SlowTick)
		{
			SlowTick = systemTimer;
			cls();
			goToPos(1, 1);
			putString("I Source:");
			goToPos(1, 2);
			putString("I Limit:");
			goToPos(1, 3);
			putString("V Source:");
			goToPos(1, 4);
			putString("V Min:");
			goToPos(1, 5);
			putString("mA Hours:");
			goToPos(12, 1);
			if (iSource < 0) iSource *= -1;
			sprintf(buff, "%6.3f", iSource / 1000.0f);
			putString(buff);
			goToPos(12, 2);
			sprintf(buff, "%6.3f", iLimit / 1000.0f);
			putString(buff);
			goToPos(12, 3);
			sprintf(buff, "%6.3f", (float)vSource / 1000.0f);
			putString(buff);
			goToPos(12, 4);
			sprintf(buff, "%6.3f", vMin / 1000.0f);
			putString(buff);
			goToPos(12, 5);
			sprintf(buff, "%6.2f", maHours / 3600.0f);
			putString(buff);

			sprintf(buff, "I: %.2f V: %.2f", iLimit / 1000.0f, vSource / 1000.0f);
			LCD_Position(0, 0);
			LCD_PrintString(buff);
			sprintf(buff, "Imeas: %.2f", iSource / 1000.0f);
			LCD_Position(1, 0);
			LCD_PrintString(buff);

			if (floatBuff[incCharIndex] == '\0')
			{
				fiLimit = atoff(floatBuff + 1);
				switch (toupper(floatBuff[0]))
				{
				case 'I':
					if (fiLimit > 4.000 ||
						fiLimit < 0.0) fiLimit = 0.0;
					iLimit = 1000.0*fiLimit;
					break;
				case 'V':
					vMin = 1000.0*fiLimit;
					break;
				case 'E':
					OutputEnable(fiLimit == 1);
					break;
				case 'R':
					maHours = 0;
					break;
        case 'B':
          Bootloadable_Load();
          CySoftwareReset();
          break; // We'll never see this because the previous line resets the
                 //  processor.
				default:
					break;
				}

				memset(floatBuff, 1, 64);
				incCharIndex = 0;
			}
		}
	}
}

void PIDIsr_Interrupt_InterruptCallback()
{
	systemTimer++;
	DoPid();
}


void DoPid()
{
	static int error = 0;
	static int integral = 0;
	static int32_t iSourceRaw = 0;
	static uint16_t grossSetPoint = 0;
	static uint16_t fineSetPoint = 0;
	static int setPoint = 0;
	static int i;
	static int loopCount = 0;

	iSourceRaw = 0;
	for (i = 0; i < 10; i++)
		iSourceRaw += CurrentReadings[i];

	iSource = I_Source_ADC_CountsTo_mVolts(iSourceRaw);

	error = iLimit - iSource;
	integral = integral + error;
	setPoint = (KPN * iLimit) / KPD + (KIN * integral) / KID + 2000; // Use feed forward plus integral
	if (setPoint < 0)
		setPoint = 0;

	// setPoint is a voltage. We need to convert that
	//  into an integer that can be fed into our DACs.
	// First, find our grossSetPoint. This is a largish voltage that
	//  represents a coarse 0-4V offset in 16mV steps.
	grossSetPoint = (int)(setPoint / 16);
	// We want to limit our gross offset to 255, since it's an 8-bit
	//  DAC output.
	if (grossSetPoint > 255)
		grossSetPoint = 255;
	// Now, find the fineSetPoint. This is a 4mV step 8-bit DAC which
	//  allows us to tune the set point a little more finely.
	fineSetPoint = (setPoint - grossSetPoint * 16) / 4;
	if (fineSetPoint > 255)
		fineSetPoint = 255;

	// Finally, one last check: if the source voltage is below vMin,
	//  or the total power is greater than 15W,
	//  disable.
	if ((vSource < vMin) ||
		(vSource * iLimit > 15000000))
		OutputEnable(false);

	if (enableOutput == false)
	{
		error = 0;
		integral = 0;
		grossSetPoint = 0;
		fineSetPoint = 0;
	}
	else
	{
		if (loopCount++ == 100)
		{
			maHours += iSource;
			loopCount = 0;
		}
	}

	Offset_SetValue(grossSetPoint);
	Gate_Drive_Tune_SetValue(fineSetPoint);
}

void OutputEnable(bool v)
{
	enableOutput = v;
	if (enableOutput)
		Output_On_LED_Write(1);
	else
		Output_On_LED_Write(0);
}

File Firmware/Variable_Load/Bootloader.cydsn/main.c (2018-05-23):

/* ========================================
 *
 * Copyright YOUR COMPANY, THE YEAR
 * All Rights Reserved
 * UNPUBLISHED, LICENSED SOFTWARE.
 *
 * CONFIDENTIAL AND PROPRIETARY INFORMATION
 * WHICH IS THE PROPERTY OF your company.
 *
 * ========================================
*/
#include "project.h"

void putString(const char *buffer);


#define USBUART_BTLDR_OUT_EP_1 0x03
#define USBUART_BTLDR_IN_EP_1  0x02

static uint8  USBUART_started = 0u;

int main(void)
{
  CyGlobalIntEnable;
  if (Bootloader_GET_RUN_TYPE == Bootloader_START_BTLDR) Bootloader_Start();
  else 
  {
    Bootloader_SET_RUN_TYPE(Bootloader_START_APP);
    CySoftwareReset();
  }
  for(;;)
  {
  }
}

void putString(const char *buffer)
{
  if (0 != (USBUART_LINE_CONTROL_DTR & USBUART_GetLineControl()) )
  {
    while (0u == USBUART_CDCIsReady());
    USBUART_PutString(buffer);
  }
}

void CyBtldrCommStart(void)
{
  USBUART_Start(0, USBUART_5V_OPERATION);
}

void CyBtldrCommStop(void)
{
  USBUART_Stop();
}

void CyBtldrCommReset(void)
{
  USBUART_CDC_Init();
}

cystatus CyBtldrCommWrite(uint8* pData, uint16 size, uint16 *count, uint8 timeOut) CYSMALL                                                            
{
    cystatus retCode;
    uint16 timeoutMs;
	uint16 bufIndex = 0;
	uint8 transfer_Size;
	*count = 0;
    timeoutMs = ((uint16) 10u * timeOut);  /* Convert from 10mS check to number 1mS checks */
    while(bufIndex < size)
	{
		if ((size -bufIndex) >  USBUART_BTLDR_SIZEOF_READ_BUFFER)
		{
			transfer_Size = USBUART_BTLDR_SIZEOF_READ_BUFFER;
		}
		else 
		{
			transfer_Size = (size -bufIndex);
		}
		/* Enable IN transfer */
    	USBUART_LoadInEP(USBUART_BTLDR_IN_EP_1, &pData[bufIndex], transfer_Size);
		/* Wait for the master to read it. */
   		while ((USBUART_GetEPState(USBUART_BTLDR_IN_EP_1) == USBUART_IN_BUFFER_FULL) &&
           (0u != timeoutMs))
    	{
        	CyDelay(1);
        	timeoutMs--;
    	}
		if (USBUART_GetEPState(USBUART_BTLDR_IN_EP_1) == USBUART_IN_BUFFER_FULL)
    	{
        	retCode = CYRET_TIMEOUT;
			break; 
    	}
	    else
	    {
	        *count += transfer_Size;
	        retCode = CYRET_SUCCESS;
			bufIndex  += transfer_Size;
	    }
	}
		
    return(retCode);
}

cystatus CyBtldrCommRead(uint8* pData, uint16 size, uint16 *count, uint8 timeOut) CYSMALL
                                                            
{
    cystatus retCode;
    uint16 timeoutMs;

    timeoutMs = ((uint16) 10u * timeOut);  /* Convert from 10mS check to number 1mS checks */
    
    if (size > USBUART_BTLDR_SIZEOF_WRITE_BUFFER)
    {
        size = USBUART_BTLDR_SIZEOF_WRITE_BUFFER;
    }

    /* Wait on enumeration in first time */
    if (0u != USBUART_started)
    {
        /* Wait for Device to enumerate */
        while ((0u ==USBUART_GetConfiguration()) && (0u != timeoutMs))
        {
            CyDelay(1);
            timeoutMs--;
        }
        
        /* Enable first OUT, if enumeration complete */
        if (0u != USBUART_GetConfiguration())
        {
            (void) USBUART_IsConfigurationChanged();  /* Clear configuration changes state status */
            CyBtldrCommReset();
            USBUART_started = 0u;
        }
    }
    else /* Check for configuration changes, has been done by Host */
    {
        if (0u != USBUART_IsConfigurationChanged()) /* Host could send double SET_INTERFACE request or RESET */
        {
            if (0u != USBUART_GetConfiguration())   /* Init OUT endpoints when device reconfigured */
            {
                CyBtldrCommReset();
            }
        }
    }
    
    timeoutMs = ((uint16) 10u * timeOut); /* Re-arm timeout */
    
    /* Wait on next packet */
    while((USBUART_GetEPState(USBUART_BTLDR_OUT_EP_1) != USBUART_OUT_BUFFER_FULL) && \
          (0u != timeoutMs))
    {
        CyDelay(1);
        timeoutMs--;
    }

    /* OUT EP has completed */
    if (USBUART_GetEPState(USBUART_BTLDR_OUT_EP_1) == USBUART_OUT_BUFFER_FULL)
    {
        *count = USBUART_ReadOutEP(USBUART_BTLDR_OUT_EP_1, pData, size);
        retCode = CYRET_SUCCESS;
    }
    else
    {
        *count = 0u;
        retCode = CYRET_TIMEOUT;
    }
    
    return(retCode);
}











/*
cystatus CyBtldrCommRead(uint8 *buffer,
                         uint16 size,
                         uint16 *count,
                         uint8 timeOut)
{
  uint8 timer = 0;
  
  if (0u != USBUART_GetConfiguration())
  {
    while (timer++ < timeOut)
    {
      if (0u != USBUART_DataIsReady())
      {
        *count += USBUART_GetAll(buffer);
        if (*count >= size) return CYRET_SUCCESS;
        else timer = 0;
      }
    }
  }
  return CYRET_TIMEOUT;
}

cystatus CyBtldrCommWrite(uint8* buffer, 
                          uint16 size, 
                          uint16* count, 
                          uint8 timeOut)
{
  uint8 timer = 0;
  if (0u != USBUART_GetConfiguration())
  {
    while (timer++ < timeOut) 
    {
      if (USBUART_CDCIsReady())
      {
        if (size > 64)
        {
          *count += 64;
          size -= 64;
          
          USBUART_PutData(buffer + *count, 64);
        }
        else
        {
          USBUART_PutData(buffer + *count, size);
          while (USBUART_CDCIsReady() == 0)
          {}
          USBUART_PutData(NULL, 0);
          return CYRET_SUCCESS;
        }
      }
    }
  }
  return CYRET_TIMEOUT;
}*/

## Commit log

2017-08-15 Removed header for CT keypad
    [Variable_Load.brd, Variable_Load.sch]
2017-08-17 Post review, pre attempting to get to two layers
    [Variable_Load.brd, Variable_Load.sch]
2017-08-17 Made into a two-layer design
    [Variable_Load.brd]
2017-08-23 Corrections from QC double check
    [Variable_Load.brd, Variable_Load.sch]
2017-09-01 Replace USB jack with newer, bossed design
    [Variable_Load.brd, Variable_Load.sch]
2017-10-02 Add firmware, latest changes to HW
    [Variable_Load.brd, Variable_Load.sch]
2017-10-03 Changes from design review
    [Variable_Load.brd, Variable_Load.sch]
2017-10-03 Change ON label to LOAD_ON
    [Variable_Load.brd]
2017-11-14 Firmware changes after red board
2017-11-20 Changes for 2nd proto round
    [Variable_Load.brd, Variable_Load.sch]
2017-11-28 Added resistor divider for contrast
    [Variable_Load.brd, Variable_Load.sch]
2017-11-28 Change font to vector on schematic
    [Variable_Load.sch]
2018-02-19 Fix issue with firmware, add readme and license files
    [13781-Variable_Load-panel.v10.brd]
2018-03-04 Change to use integer math for PID. Change to use feedforward in PID. Change to trigger ADC with hardware clock and do PID calcualtion in ISR. Change to average voltage ADC readings to reduce noise.
    [main.c]
2018-03-04 Improve precision of current measurement. Add ability to set vMin and enable/disable load from terminal.
2018-03-05 Improve precision of current measurement. Add ability to set vMin and enable/disable load from terminal. Use internal reference for source voltage ADC (rather than 1/2 the supply voltage). This make 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
2018-03-05 Change to averge current reading. Change to use internal reference for voltage measuremnt rather than supply/2 to improve accuracy. This reduces the range to about 20V with the 10:1 divider. Ideally 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
2018-03-05 Fixed current measurment averaging. There are a number of subtleties with regard to DMA and the DelSigADC. Fortunately there is a Cypress app note that describes how to make it work. Added mAhour com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
    [main.c]

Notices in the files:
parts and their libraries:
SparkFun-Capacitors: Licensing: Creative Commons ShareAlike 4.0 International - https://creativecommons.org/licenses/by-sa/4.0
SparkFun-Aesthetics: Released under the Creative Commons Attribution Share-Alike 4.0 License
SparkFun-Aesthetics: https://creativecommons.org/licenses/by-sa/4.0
